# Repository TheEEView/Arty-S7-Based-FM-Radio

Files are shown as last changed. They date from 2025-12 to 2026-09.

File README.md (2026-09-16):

# Arty-S7-Based-FM-Radio
FPGA Based FM Radio with custom RF frontend using an Arty S7 off the shelf development board spanning the 88MHz to 108MHz passband with crisp high-end audio (16-bit stereo). The RF front end downmixes and filters the received FM signal down to 100kHz before the ADC via a neat 4th order Butterworth MFB topology and other goodies.

This is the 2nd major gen design (First generation with 2 iterations were an all in one board with a Spartan 7 onboard), hence the v2 sch/pcb nomenclature. I will release the other version as another project.

The PCB is a 4 layer board with a S/G/G/S stackup using primarily 0402 components and high speed design principles. Routing is on the top and bottom layers only.

Please See docs/fm-radio-sysarch.png for a simple system block design and docs/fm-radio-fpga-arch for the FPGA architecture.

Vivado 2025.2.1, KiCAD 10 and Octave have been used.

Source is available in VHDL (IEEE Std 1076-2019).

This has been a WIP since Dec 2023. 

## How to generate Vivado Project
source logic/impl/create_project.tcl

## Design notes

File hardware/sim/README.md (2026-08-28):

# Analog front end simulation

ngspice models of the `analog_front_end_v2` signal chain, built so the
board can be swept, corner-cased and Monte-Carlo'd before committing to
another spin.

```
./run.sh          # nominal benches, ~5 s
./run.sh mc       # + Monte Carlo (1300 trials), ~13 s
./run.sh e2e      # + end-to-end transient level plan, ~35 s
./run.sh all      # everything
```

Needs only `ngspice` (developed on 42) and python3 for `mcstat.py` —
standard library only, no numpy.

## What is modelled

Component values come from `analog_front_end_v2.kicad_sch`, extracted with
`kicad-cli sch export netlist`, and live in **one** place, `common.inc`.
Refdes names match the schematic. The two shared subnetworks,
`bpf.inc` and `ifchain.inc`, are included by both the nominal and the
Monte Carlo decks so the two cannot drift apart.

```
J1 ─ 5-pole LC BPF ─ U18 ─ U1 ─ U19 ─ U2 ─ U20 ─ U3 ─ U21 ─ U4 ─ U7 ─ T1
                     pad   LNA  pad   LNA  pad   LNA  pad   LNA  pad  balun
                                                                       │
   MCP33131 ◄─ R47/C76 ◄─ U26 MFB ◄─ U25 MFB ◄─ C65/66 ◄─ R33/34 ◄─ LT5560 ◄┘
                                                                     ▲
                                                        ADF4351 ─────┘
```

| bench | what it answers |
|---|---|
| `tb_lna_cal.cir`  | ADL5531 model vs datasheet (gain, NF) |
| `tb_bpf.cir` | RF bandpass shape, insertion loss, out-of-band rejection |
| `tb_rf_chain.cir` | cascade gain and noise figure, antenna to mixer |
| `tb_padsweep.cir` | what the U18 input pad costs in NF |
| `tb_lo_drive.cir` | does the ADF4351 deliver enough LO to the LT5560 |
| `tb_if_chain.cir` | anti-alias response against the real 779.2 ksps plan |
| `tb_e2e.cir` | full time-domain level plan, antenna dBm to ADC volts |
| `mc_bpf.cir` | Monte Carlo: bandpass |
| `mc_rf_chain.cir` | Monte Carlo: cascade gain and NF |
| `mc_if_chain.cir` | Monte Carlo: anti-alias filter |

The operating point is taken from the RTL, not guessed: `fs = 779.2 ksps`
(`mpc33131_adc_driver.vhd`), IF pinned at 100 kHz and the LO one IF below
the station (`adf4351_driver.vhd`), so at full ±75 kHz deviation the
instantaneous IF sweeps 25 – 175 kHz (`fm_demodulator.vhd`).

## Model provenance

Everything in `models/behavioral.lib` is marked `[DS]` (from a datasheet),
`[FIT]` (calibrated by a bench in this directory) or `[ASSUMED]`.

Datasheet-backed:

- **LT5560** — `docs/LT5560f.pdf` Table 2 gives the differential signal
  input as 28.5 + j0.8 Ω at 70 MHz, modelled as 28.5 Ω + 1.8 nH. This
  confirms the board's C59/L13/L14 network: it transforms the 50 Ω balun
  secondary to 28.3 Ω, which is the right target. LO port 180 Ω needing
  240 mV<sub>rms</sub>, also from the datasheet.
- **ADL5531** — 20 dB, NF 2.6 dB, OP1dB +19.5 dBm. The input match is a
  *noiseless* synthesised 50 Ω (a real shunt resistor floors the model at
  NF = 3.0 dB and the part does 2.6 dB); `rnf` and `vsat` are then fitted
  to hit NF and OP1dB. `tb_lna_cal.cir` re-checks both.

Assumed, and worth your review:

- **LT5560 conversion transconductance.** Backed out of the 2.4 dB
  conversion-gain figure *assuming the datasheet test circuit presents a
  400 Ω differential IF load* → `gm = 19.4 mA/V`. The absolute level plan
  in `tb_e2e.cir` scales directly with this: a 3× error moves the clip
  point 10 dB. Everything else (filter shapes, NF, LO drive, all the
  Monte Carlo spreads) is independent of it.
- **LTC6362** GBW 34 MHz and ±1.2 V output swing per pin. The GBW is far
  enough above the 222 kHz corner not to matter; the swing limit *does*
  set the clip point in `tb_e2e.cir`.
- **Inductor Q = 40** at 103 MHz for the 0402 bandpass parts. This matters
  a lot — see below. Set `QL` in `bpf.inc` to whatever your actual parts do.

Not modelled: layout parasitics, and the LT5560's open-collector output
bias current (the real part sources ~6 mA per pin, so R33/R34 = 330 Ω drop
about 2 V from the 5 V rail — a headroom question this deck cannot answer).

## What the nominal sim says

**The bandpass costs 3.1 dB, not 0.5 dB.** With ideal inductors the filter
loses 0.5 dB in band. With Q = 40 it loses 3.1 dB, and the two 500 nH
series-arm inductors (L2, L4) dominate — they carry the most reactance so
they burn the most ESR. That 2.6 dB lands directly on the noise figure.
Set `QL=1e9` in `bpf.inc` to see the ideal case.

**Cascade NF is 10.7 dB, and 5 dB of it is the U18 pad.** The pads are
populated with `PAT1220-C-5DB-T5`. Anything ahead of U1 adds to NF one for
one, and `tb_padsweep.cir` shows exactly that:

```
 pad_dB   chain_gain_dB   cascade_NF_dB
    0          54.06           5.57
    5          49.06          10.71     <- as populated
   10          44.06          15.73
```

**The bandpass is fine but wide.** Geometric centre 102.9 MHz, −3 dB band
90.9 – 116.4 MHz, flat to 0.33 dB across 100 – 106. That is a 25 %
fractional bandwidth, which is why rejection at 88 MHz — the bottom of the
FM band, full of strong local transmitters — is only 10.4 dB. Out at
144 MHz it is 44 dB.

**The anti-alias filter is 222 kHz, not 320 kHz.** The header comment in
`fm_demodulator.vhd` says "320 kHz anti aliasing filter"; the two MFB
sections as built give a −3 dB corner of 222 kHz. The shape is very close
to a 4th-order Butterworth (0.18 dB peaking), slightly steeper than
textbook because the mixer's own R33/R34/C64 pole at ~241 kHz makes the
cascade effectively 5th order. Rejection over 604 – 754 kHz, the band that
folds onto the wanted 25 – 175 kHz IF at 779.2 ksps, is 38.6 dB.

**0.80 dB of tilt across the IF swing.** The filter is 0.14 dB down at
25 kHz and 0.80 dB down at 175 kHz. A slope detector turns amplitude tilt
into demodulated output, so this adds to the ~5 % full-deviation
distortion the RTL header already accounts for.

## Two things worth acting on

**1. The ADF4351 is programmed to under-drive the mixer LO.**
`adf4351_driver.vhd` declares `OUTPUT_POWER : natural := 0` (−4 dBm) and
`toplevel.vhd` does not override it. Through R51/C63/R32/C62 the network
delivers 0.626 V per volt of source EMF, so:

```
  ADF4351 setting   LO port mVrms   (LT5560 wants 240)
     -4 dBm             177          <- default, 2.7 dB short
     -1 dBm             250          marginal
     +2 dBm             352          comfortable
     +5 dBm             498
```

Passing `OUTPUT_POWER => 2` in the `toplevel.vhd` generic map fixes it.
Worth confirming on the bench before changing anything — an under-driven
LT5560 loses conversion gain and degrades NF rather than failing outright,
so it would not show up as a dead radio.

**2. The chain runs out of headroom long before the ADC does.**
`tb_e2e.cir` sweeps antenna power through the whole chain into the ADC pins:

```
 Pant_dBm   IF_pk_V   pct_FS
   -100      0.091      3.6
    -90      0.287     11.5
    -80      0.908     36.3
    -70      2.396     95.8    <- clipped
    -60      2.398     95.9
```

The LTC6362 output swing runs out around −75 dBm at the antenna; U4 hits
its own 1 dB compression near −41 dBm. With a cascade NF of 10.7 dB the
noise floor in a 200 kHz channel is about −110 dBm, so the usable window
is roughly 30 dB wide against an FM environment that spans −100 to
−20 dBm. Strong local stations will overload this front end.

This is the same knob as finding 1: four cascaded 20 dB gain blocks with
only 5 dB pads between them is +49 dB of RF gain. Trading pad values buys
headroom at the cost of NF, and `tb_padsweep.cir` plus `tb_e2e.cir`
together let you price that trade. Note the caveat above — the absolute
clip point scales with the assumed LT5560 conversion gain, so measure the
IF level on a real board before redesigning around it. The *shape* of the
problem (gain distribution) does not depend on that assumption.

## Monte Carlo

Each `mc_*.cir` has a knobs block at the top of its `.control` section:

```
let trials = 500
let tolc   = 0.02      $ capacitors
let toll   = 0.03      $ inductors
let tolq   = 0.30      $ inductor Q spread
let dist   = 0         $ 0 = gaussian truncated at 3 sigma, 1 = uniform
setseed 20260829       $ comment out for a fresh draw each run
```

Both halves of the differential IF pair are drawn independently, which is
what actually happens on a board and what creates the gain-mismatch
spread. Each deck writes `MC,...` CSV lines to stdout; `mcstat.py` turns
those into statistics, histograms and yield against limits:

```
./mcstat.py out/mc_if_chain.csv --limit fold_worst_db:max=-35 --hist f3db_hz
```

Results as built (500 / 300 / 500 trials, gaussian at 3σ):

| metric | mean | σ | p1 … p99 |
|---|---|---|---|
| BPF worst in-band IL | −3.24 dB | 0.34 | −4.16 … −2.54 |
| BPF ripple 100–106 | 0.33 dB | 0.067 | 0.18 … 0.49 |
| BPF rejection at 88 MHz | −10.47 dB | 0.74 | −12.2 … −8.8 |
| chain gain at 103 MHz | 48.97 dB | 0.42 | 47.97 … 49.80 |
| cascade NF at 103 MHz | 10.77 dB | 0.32 | 10.20 … 11.67 |
| AA −3 dB corner | 222.0 kHz | 0.72 k | 220.2 … 223.8 k |
| AA fold-band rejection | −38.71 dB | 0.12 | −38.97 … −38.44 |
| IF tilt at 175 kHz | −0.80 dB | 0.029 | −0.87 … −0.72 |

The filters are not tolerance-limited. The IF chain in particular barely
moves — 0.12 dB of σ on alias rejection — because it is all 1 % resistors
and 2 % C0G in a low-Q topology.

The bandpass insertion-loss spread is driven more by **inductor Q than by
component values**. Re-running `mc_bpf.cir` with `tolq = 0` (Q pinned at
40) drops σ from 0.34 dB to 0.17 dB and pulls the worst trial in from
−5.04 dB to −3.80 dB, so Q spread contributes roughly 0.29 dB of the
0.34 dB in quadrature and the L/C tolerances the remaining 0.17 dB. If you
want insertion loss held tightly, specify Q on L2 and L4 — tightening the
value tolerance buys about half as much.

## Adding a scenario

- **Temperature**: `.options TEMP=` in the deck, or `alter` the values from
  a tempco in the Monte Carlo loop.
- **Different pad values**: edit `PAD_IN` / `PAD_12` / … in `common.inc`.
- **Blocking / two-tone**: add a second `SIN` source in `tb_e2e.cir` at,
  say, 88 MHz and watch the 100 kHz IF amplitude drop as the blocker
  desensitises the chain. The compressing `ADL5531` subckt (not
  `ADL5531_LIN`) is already used there, so intermodulation shows up.
- **A different LT5560 conversion gain**: `XMIX ... LT5560 gm=<value>`.

## ngspice notes

Three things cost time while building this; they are worth knowing.

- `meas ac f3 when h=gpass-3 fall=1` does **not** evaluate the expression.
  It silently measures something else. Normalise first: `let hn = h - gpass`
  then `meas ac f3 when hn=-3 fall=1`.
- Only one `let` per line. `let a=1  let b=2` swallows the rest of the line
  into `a`'s right-hand side and `b` never exists.
- After `noise`, the current plot is the *integrated* noise plot; the
  spectral density is the one before it, so use `setplot previous`.
  `setplot noise1` re-selects the first noise run every time, which
  silently returns stale data inside a loop.
- `unif()` and `gauss()` are not available in the control language in
  ngspice 42; `sgauss(0)` and `sunif(0)` are, and the decks build
  truncated distributions from those.

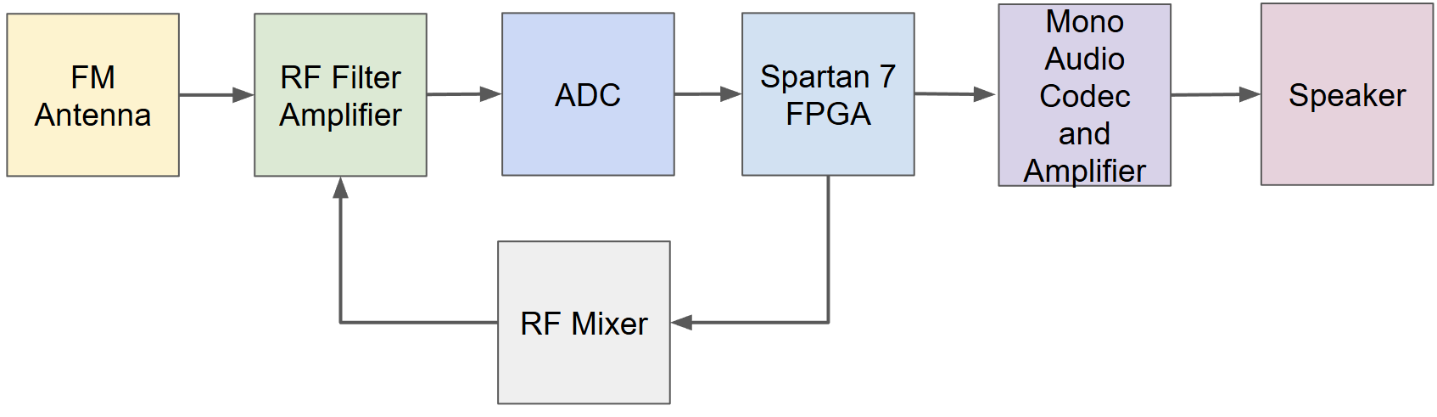
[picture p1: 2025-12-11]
docs/fm-radio-sysarch.png

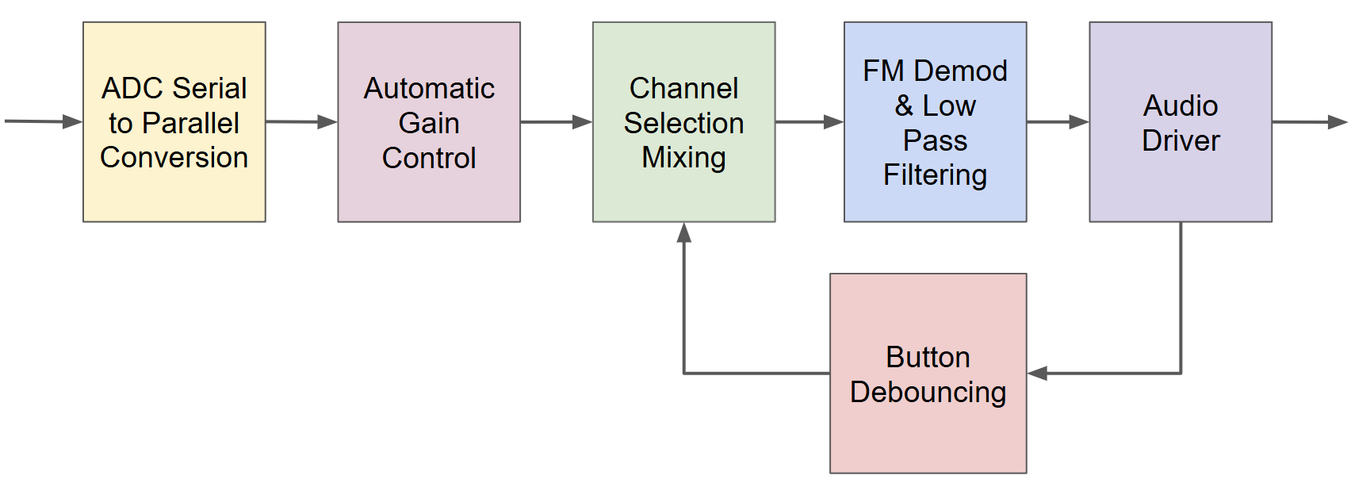
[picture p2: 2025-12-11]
docs/fm-radio-fpga-arch.png

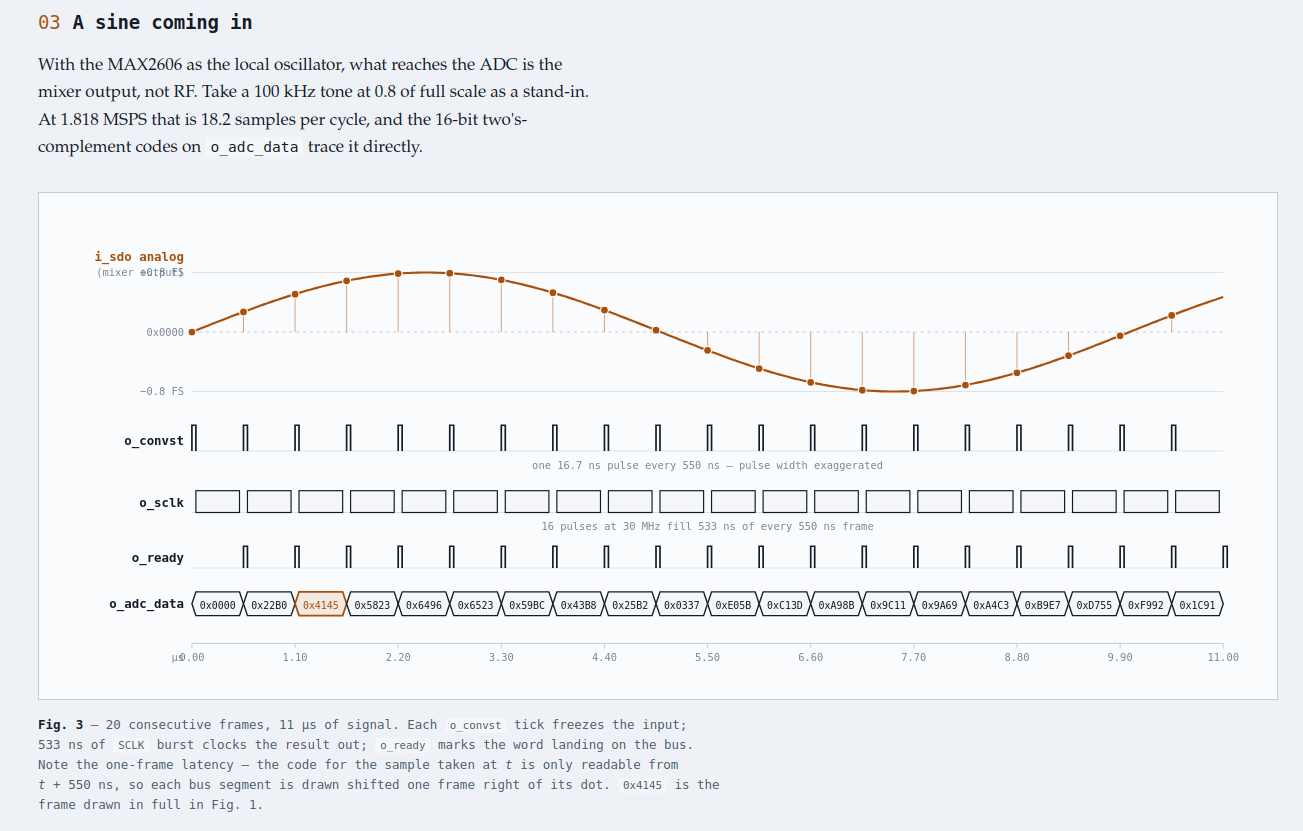
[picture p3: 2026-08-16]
docs/adc_sine_wave.png

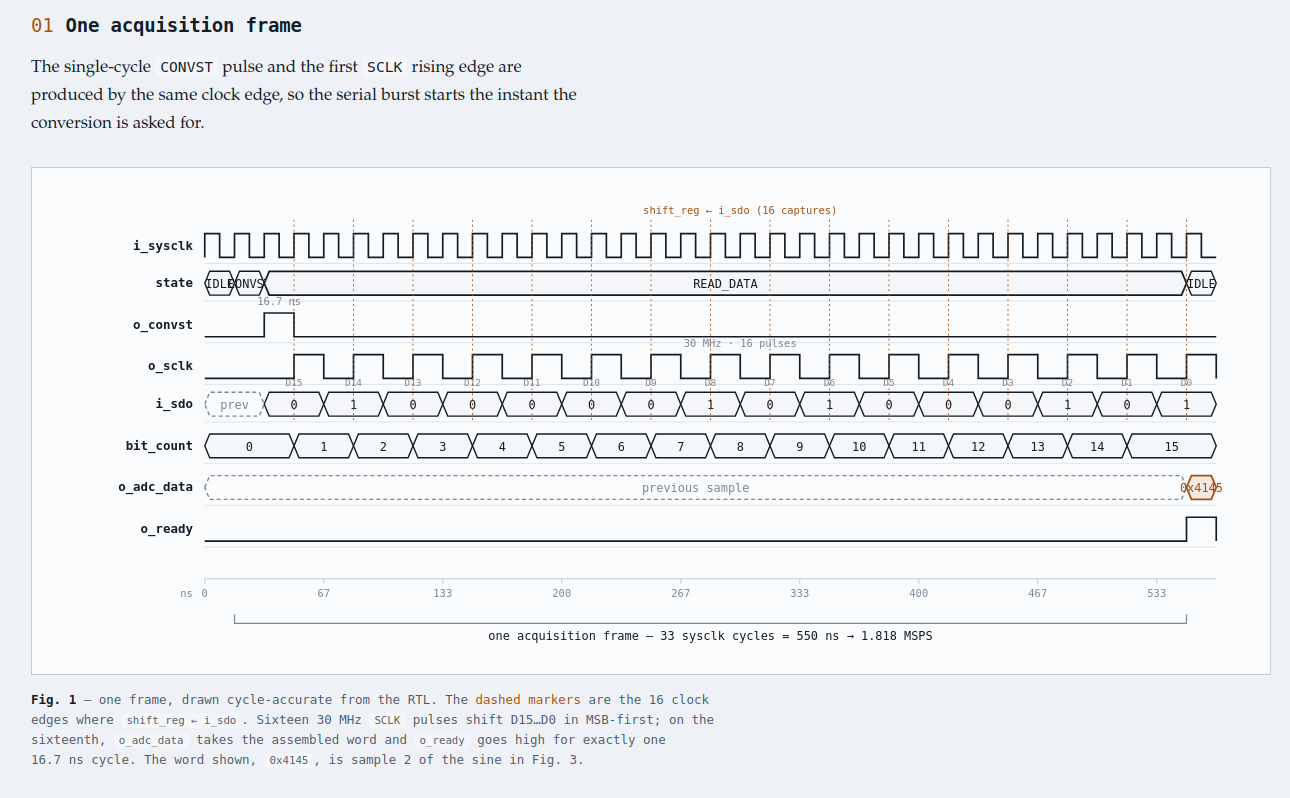
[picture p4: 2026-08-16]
docs/adc_conversion_timing.png

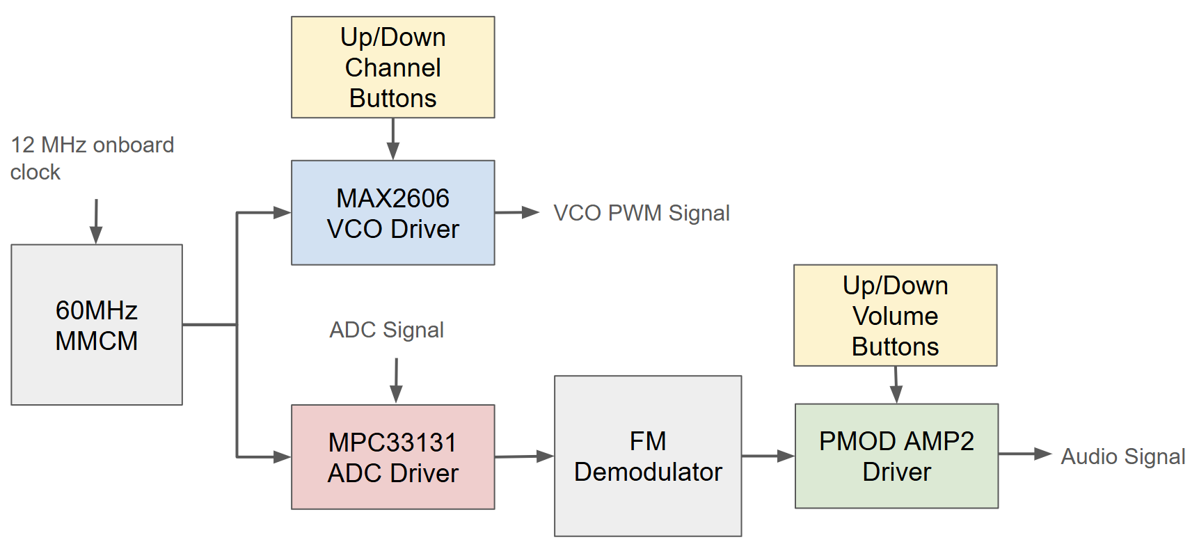
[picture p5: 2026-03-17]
docs/fm-module-composition.png

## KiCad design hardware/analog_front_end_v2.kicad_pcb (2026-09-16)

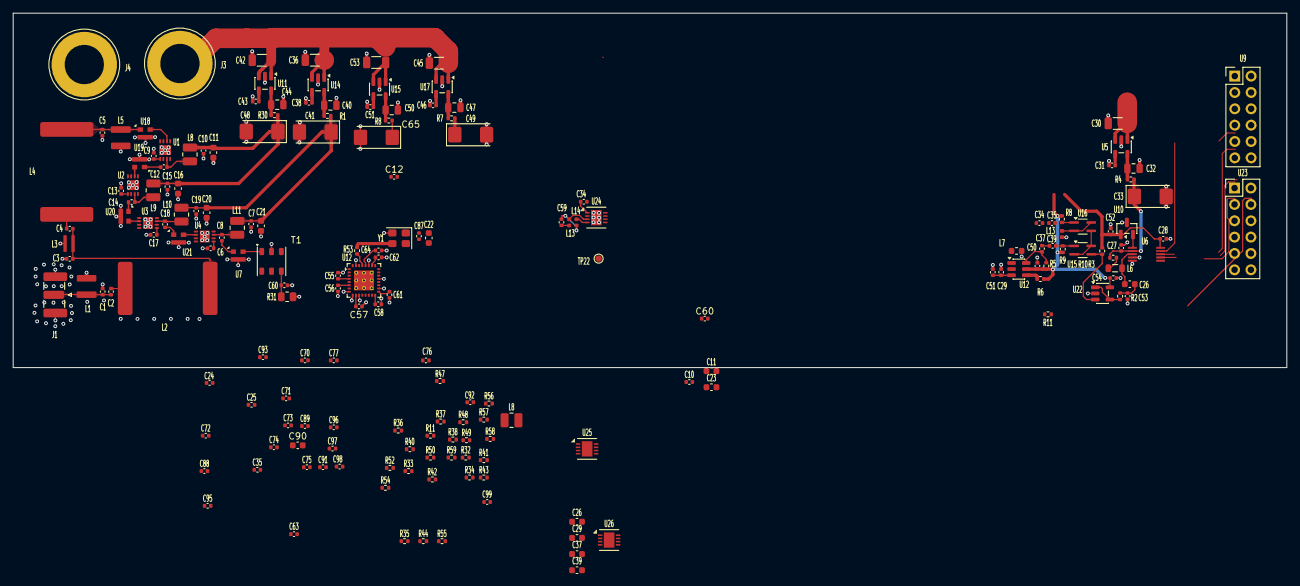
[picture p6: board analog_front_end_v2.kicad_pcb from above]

Board: 4 copper layers, 197.9 x 55.1 mm, 184 parts (0 on the bottom side), 104 nets.

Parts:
C1, C5: 75p_50V; C_0402_1005Metric
C2, C4: 4p8_50V; C_0402_1005Metric
C3: 220p_50V; C_0402_1005Metric
C6, C9, C13, C17, C24, C25, C29, C60: 1n_50V; C_0402_1005Metric
C7, C8, C10, C10#2, C12, C12#2, C14, C15, C18, C19, C31, C34#2, C35, C38, C43, C46, C50, C51#2, C53#2: 10n_25V; C_0402_1005Metric
C11, C11#2, C16, C20, C21, C22, C23, C26, C26#2, C29#2, C37, C39#2: 1u_16V; C_0603_1608Metric
C27, C28, C51, C52, C54, C55, C56, C57, C58, C61, C62, C64, C87, C88, C92, C93, C95, C96, C97, C98, C99: 100n_25V; C_0402_1005Metric
C30, C36, C42, C45, C53: 10u_50V; C_1206_3216Metric
C32, C40, C44, C47, C50#2: 10u_16V; C_0805_2012Metric
C33, C41, C48, C49, C65: 47u_16V; CP_EIA-6032-15_Kemet-U
C34, C35#2, C37#2, C39: 5p1_50V; C_0402_1005Metric
C59: 27p; C_0402_1005Metric
C60#2: 1n; C_0402_1005Metric
C63: 100p_250V; C_0402_1005Metric
C70: 390p; C_0402_1005Metric
C71, C72: 130p; C_0402_1005Metric
C73: 910p; C_0402_1005Metric
C74, C75: 56p; C_0402_1005Metric
C76, C77: 1n8; C_0402_1005Metric
C89: 1n5; C_0402_1005Metric
C90: 15n; C_0603_1608Metric
C91: 150p; C_0402_1005Metric
J1: Conn_Coaxial; SMA_Samtec_SMA-J-P-H-ST-EM1_EdgeMount
J3, J4: Conn_01x01_Socket; Banana_Jack_1Pin
L1, L5: 36n; 1111SQ-36N
L2, L4: 500n; 2929SQ-501GEC
L3: 11n2; 0807SQ-11N
L6: 10n; L_0805_2012Metric
L7: 390n; L_0603_1608Metric
L8, L8#2, L9, L10, L11: 470n; L_1008_2520Metric
L13: 100n; L_0402_1005Metric
L13#2, L14: 18n; L_0402_1005Metric
R1, R4, R7, R8#2, R30: 0R; R_0402_1005Metric
R2, R3, R5, R6, R11#2: 100; R_0402_1005Metric
R8, R9, R10: 3.3k; R_0402_1005Metric
R11: 5.1k; R_0402_1005Metric
R31: 3R0; R_0805_2012Metric
R32: 162R; R_0402_1005Metric
R33, R34: 330R; R_0402_1005Metric
R35, R36, R37, R38, R41, R42, R43, R44: 1k00; R_0402_1005Metric
R40, R56, R57, R58: 4k02; R_0402_1005Metric
R47, R48: 22R0; R_0402_1005Metric
R49, R50: 20k0; R_0402_1005Metric
R52, R59: 50R; R_0402_1005Metric
R53: 33R; R_0402_1005Metric
R54: 1k37; R_0402_1005Metric
R55: 6k19; R_0402_1005Metric
T1: WBC1-1TL 1:1; WBC1-1TLC
TP22: TestPoint; TestPoint_Pad_D1.0mm
U1, U2, U3, U4: ADL5531
U5: LP2985-1.8; SOT-23-5
U6: MCP33131
U7, U18, U19, U20, U21: PAT1220-C-0DB; RF_Attenuator_Susumu_PAT1220
U9, U23: PMOD 2x6 2.54mm pitch; PinHeader_2x06_P2.54mm_Vertical
U10: MAX6002; SOT-23
U11, U14, U15#2: LP2985-5.0; SOT-23-5
U12: MAX2606; SOT-23-6
U12#2: ADF4531; ADF4351_LFCSP-32_5x5mm_P0.5mm_EP3.1x3.1mm
U15, U16: BFP540ESD; SOT-343_SC-70-4_Handsoldering
U17: LP2985-3.3; SOT-23-5
U22: MCP6286; SOT-23-5
U24: LT5560; DFN-8-1EP_3x3mm_P0.5mm_EP1.66x2.38mm
U25, U26: LTC6362; DFN-8-1EP_3x3mm_P0.5mm_EP1.66x2.38mm
Y1: 12.8MHz TCXO; Oscillator_SMD_Abracon_ASE-4Pin_3.2x2.5mm

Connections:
1V8: C27.1, C33.1, R3.1, R4.2, U6.2 (AVDD)
3.3V_PMOD: U9.6, U9.12, U23.6, U23.12
3V3: C22.1, C28.1, C49.1, C50.1, C52.2, C54.1, C55.1, C56.1, C57.1, C58.1, C61.1, C62.1, C64.1, C87.1, R5.2, R6.2, R7.2, R8.1, R9.1, R10.1, R52.2, R59.1, U6.10 (DVIO), U10.1 (IN), U12.5 (VCC), U12#2.4 (CE), U12#2.6 (VP), U12#2.10 (AVDD), U12#2.16 (VVCO), U12#2.17 (VVCO), U12#2.26 (PDBRF), U12#2.28 (DVDD), U12#2.32 (SDVDD), U22.5 (Vdd), Y1.1 (EN), Y1.4 (Vdd)
5V_LNA1: C10.1, C10#2.1, C11.1, C11#2.1, C15.1, C16.1, C48.1, L8.2, L8#2.2, L9.2, R30.2
5V_LNA2: C7.1, C19.1, C20.1, C21.1, C41.1, L10.2, L11.2, R1.2
5V_MIX: C23.1, C24.1, C37.1, C39#2.1, C65.1, C97.1, C98.1, C99.1, R8#2.2, R33.1, R34.2, U24.2 (EN), U24.7 (VCC), U25.3 (V+), U25.7 (~SHDN), U26.3 (V+), U26.7 (~SHDN)
ADC_AIN_N: C77.1, R48.2, U6.4 (AIN-)
ADC_AIN_P: C76.2, R47.2, U6.3 (AIN+)
ADC_CONVST: U6.6 (CONVST), U9.9
ADC_SCLK: U6.8 (SCLK), U9.3
ADC_SDI: U6.9 (SDI), U9.1
ADC_SDO: U6.7 (SDO), U9.7
ADC_VCM: C29#2.1, R2.2, U25.2 (VOCM), U26.2 (VOCM)
ADC_VREF_2V5: R49.1, U6.1 (Vref), U10.2 (OUT)
CP_OUT: C89.1, R54.1, R55.1, U12#2.7 (CPOUT)
GND: C1.2, C3.2, C5.2, C6.2, C7.2, C9.2, C10.2, C10#2.2, C11.2, C11#2.2, C13.2, C15.2, C16.2, C17.2, C19.2, C20.2, C21.2, C22.2, C23.2, C24.2, C26.2, C27.2, C28.2, C29.1, C29#2.2, C30.1, C31.1, C32.1, C33.2, C35.1, C36.1, C37.2, C38.1, C39#2.2, C40.1, C41.2, C42.1, C43.1, C44.1, C45.1, C46.1, C47.1, C48.2, C49.2, C50.2, C50#2.1, C51.2, C51#2.1, C52.1, C53.1, C53#2.2, C54.2, C55.2, C56.2, C57.2, C58.2, C60.2, C60#2.2, C61.2, C62.2, C64.2, C65.2, C76.1, C77.2, C87.2, C88.2, C89.2, C90.2, C91.2, C92.2, C93.2, C97.2, C98.2, C99.2, J1.2 (Ext), J4.1 (Pin_1_1), L1.2, L3.2, L5.2, L7.1, L13.1, R11.2, R31.2, R32.2, R50.1, T1.2 (AB), TP22.1 (1_1), U1.9 (EP), U2.9 (EP), U3.9 (EP), U4.9 (EP), U5.2 (GND), U6.5 (GND), U7.3, U9.5, U9.11, U10.3 (GND), U11.2 (GND), U12.2 (GND), U12#2.8 (CPGND), U12#2.9 (AGND), U12#2.11 (AGNDVCO), U12#2.18 (AGNDVCO), U12#2.21 (AGNDVCO), U12#2.27 (DGND), U12#2.31 (SDGND), U14.2 (GND), U15#2.2 (GND), U17.2 (GND), U18.3, U19.3, U20.3, U21.3, U22.2 (Vss), U23.5, U23.11, U24.9 (PGND), U25.6 (V-), U25.9 (V-), U26.6 (V-), U26.9 (V-), Y1.2 (GND)
IF_N: C95.2, R36.1
IF_P: C96.2, R35.1
LO: C37#2.2, R5.1, U12.6 (OUT+)
LO_100M: C63.1, R59.2, U12#2.12 (RFOUTA+)
MIX_BIAS: C60.1, C60#2.1, R31.1, T1.4 (SC)
unnamed: C2.1, L2.1
unnamed: C3.1, C4.1, L2.2, L3.1
unnamed: C4.2, L4.1
unnamed: C5.1, L4.2, L5.1, U18.1
unnamed: C8.2, U7.1
unnamed: C12.2, C12#2.2, U19.1
unnamed: C14.2, U20.1
unnamed: C18.2, U21.1
unnamed: C26#2.1, C53#2.1
unnamed: C34.1, C35#2.1
unnamed: C34.2, C34#2.2, C63.2, R32.1
unnamed: C37#2.1, C39.1
unnamed: C70.1, R35.2, R37.1, R56.1
unnamed: C70.2, R36.2, R38.1, R40.1
unnamed: C71.1, R37.2, U25.1 (-)
unnamed: C71.2, R41.1, R56.2, U25.4 (+)
unnamed: C72.1, R38.2, U25.8 (+)
unnamed: C72.2, R40.2, R42.1, U25.5 (-)
unnamed: C73.1, R41.2, R43.1, R57.1
unnamed: C73.2, R42.2, R44.1, R58.1
unnamed: C74.1, R43.2, U26.1 (-)
unnamed: C74.2, R47.1, R57.2, U26.4 (+)
unnamed: C75.1, R44.2, U26.8 (+)
unnamed: C75.2, R48.1, R58.2, U26.5 (-)
unnamed: C90.1, R54.2
unnamed: C1.1, C2.2, J1.1 (In), L1.1
unnamed: L6.2, R3.2
unnamed: L13.2, U16.2 (E), U16.4 (E)
unnamed: T1.1 (AA), U7.2
unnamed: C59.2, L14.1, T1.3 (SA)
unnamed: C59.1, L13#2.1, T1.5 (SB)
unnamed: C9.1, U1.5 (CLIN)
unnamed: U1.2 (RFIN), U18.2
unnamed: C12.1, C12#2.1, L8.1, L8#2.1, U1.7 (RFOUT)
unnamed: C13.1, U2.5 (CLIN)
unnamed: U2.2 (RFIN), U19.2
unnamed: C14.1, L9.1, U2.7 (RFOUT)
unnamed: C17.1, U3.5 (CLIN)
unnamed: U3.2 (RFIN), U20.2
unnamed: C18.1, L10.1, U3.7 (RFOUT)
unnamed: C6.1, U4.5 (CLIN)
unnamed: U4.2 (RFIN), U21.2
unnamed: C8.1, L11.1, U4.7 (RFOUT)
unnamed: C31.2, U5.4 (BP)
unnamed: C32.2, R4.1, U5.5 (VOUT)
unnamed: C26#2.2, L6.1
unnamed: C43.2, U11.4 (BP)
unnamed: C44.2, R30.1, U11.5 (VOUT)
unnamed: L7.2, U12.1 (IND)
unnamed: R6.1, U12.4 (OUT-)
unnamed: R52.1, U12#2.13 (RFOUTA-)
unnamed: R11.1, U12#2.22 (RSET)
unnamed: C29.2, C51.1, R11#2.1, U12.3 (TUNE)
unnamed: C38.2, U14.4 (BP)
unnamed: C40.2, R1.1, U14.5 (VOUT)
unnamed: C39.2, R9.2, U15.1 (B)
unnamed: C51#2.2, U15#2.4 (BP)
unnamed: R10.2, U15.3 (C)
unnamed: C50#2.2, R8#2.1, U15#2.5 (VOUT)
unnamed: C35#2.2, R8.2, U16.1 (B)
unnamed: U15.2 (E), U15.4 (E), U16.3 (C)
unnamed: C46.2, U17.4 (BP)
unnamed: C47.2, R7.1, U17.5 (VOUT)
unnamed: R2.1, U22.1 (Vout), U22.4 (Vin-)
unnamed: L13#2.2, U24.3 (IN+)
unnamed: L14.2, U24.4 (IN-)
unnamed: C35.2, U24.8 (LO+)
unnamed: C34#2.1, U24.1 (LO-)
unnamed: C25.1, C96.1, R33.2, U24.6 (OUT+)
unnamed: C25.2, C95.1, R34.1, U24.5 (OUT-)
unnamed: R53.1, Y1.3 (OUT)
PLL_REF: R53.2, U12#2.29 (REFIN)
PLL_TEMP: C93.1, U12#2.19 (TEMP)
PLL_VCOM: C92.1, U12#2.23 (VCOM)
PLL_VREF: C88.1, U12#2.24 (VREF)
VCM_DIV: C26.1, R49.2, R50.2, U22.3 (Vin+)
VCO_DATA: U12#2.2 (DATA), U23.1
VCO_LD: U12#2.25 (LD), U23.7
VCO_LE: U12#2.3 (LE), U23.9
VCO_LOCKDET: U12#2.30 (MUXOUT), U23.10
VCO_SCLK: U12#2.1 (CLK), U23.3
VIN: C30.2, C36.2, C42.2, C45.2, C53.2, J3.1 (Pin_1_1), U5.1 (VIN), U5.3 (ON/~OFF), U11.1 (VIN), U11.3 (ON/~OFF), U14.1 (VIN), U14.3 (ON/~OFF), U15#2.1 (VIN), U15#2.3 (ON/~OFF), U17.1 (VIN), U17.3 (ON/~OFF)
VTUNE: C91.1, R55.2, U12#2.20 (VTUNE)

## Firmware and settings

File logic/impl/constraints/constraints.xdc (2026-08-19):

## Arty S7-50 (xc7s50csga324-1) constraints for the FM radio
## Package pins and schematic names taken from Digilent/digilent-xdc Arty-S7-50-Master.xdc

## 12 MHz onboard oscillator
set_property -dict { PACKAGE_PIN F14   IOSTANDARD LVCMOS33 } [get_ports { i_clk_12 }]; #IO_L13P_T2_MRCC_15 Sch=uclk
create_clock -add -name sys_clk_pin -period 83.333 -waveform {0 41.667} [get_ports { i_clk_12 }];

## Buttons
set_property -dict { PACKAGE_PIN G15   IOSTANDARD LVCMOS33 } [get_ports { i_btn_vol_up }];   #IO_L18N_T2_A23_15 Sch=btn[0]
set_property -dict { PACKAGE_PIN K16   IOSTANDARD LVCMOS33 } [get_ports { i_btn_vol_down }]; #IO_L19P_T3_A22_15 Sch=btn[1]
set_property -dict { PACKAGE_PIN J16   IOSTANDARD LVCMOS33 } [get_ports { i_btn_ch_up }];    #IO_L19N_T3_A21_VREF_15 Sch=btn[2]
set_property -dict { PACKAGE_PIN H13   IOSTANDARD LVCMOS33 } [get_ports { i_btn_ch_down }];  #IO_L20P_T3_A20_15 Sch=btn[3]

## High Speed Pmod Header JA - analog front end board (MCP33131 ADC and ADF4351 LO synthesiser)
set_property -dict { PACKAGE_PIN L17   IOSTANDARD LVCMOS33 } [get_ports { o_adc_sdi }];      #IO_L4P_T0_D04_14 Sch=ja_p[1]
set_property -dict { PACKAGE_PIN M14   IOSTANDARD LVCMOS33 } [get_ports { o_adc_sclk }];     #IO_L5P_T0_D06_14 Sch=ja_p[2]
set_property -dict { PACKAGE_PIN M16   IOSTANDARD LVCMOS33 } [get_ports { i_adc_sdo }];      #IO_L7P_T1_D09_14 Sch=ja_p[3]
set_property -dict { PACKAGE_PIN M18   IOSTANDARD LVCMOS33 } [get_ports { o_adc_convst }];   #IO_L8P_T1_D11_14 Sch=ja_p[4]

## ADF4351 LO synthesiser, three wire SPI plus lock detect, on the remaining JA pins.
## CE is expected to be tied high on the analog front end board rather than driven from here.
set_property -dict { PACKAGE_PIN L18   IOSTANDARD LVCMOS33 } [get_ports { o_pll_clk }];      #IO_L4N_T0_D05_14 Sch=ja_n[1]
set_property -dict { PACKAGE_PIN N14   IOSTANDARD LVCMOS33 } [get_ports { o_pll_data }];     #IO_L5N_T0_D07_14 Sch=ja_n[2]
set_property -dict { PACKAGE_PIN M17   IOSTANDARD LVCMOS33 } [get_ports { o_pll_le }];       #IO_L7N_T1_D10_14 Sch=ja_n[3]
set_property -dict { PACKAGE_PIN N18   IOSTANDARD LVCMOS33 } [get_ports { i_pll_lock }];     #IO_L8N_T1_D12_14 Sch=ja_n[4]

## Pmod Header JD - PmodAMP2 mono audio amplifier, plugged into the top row
## PmodAMP2 pin 1 AIN, pin 2 GAIN, pin 3 NC, pin 4 active low shutdown (PmodAMP2 reference
## manual Table 1), so pin 3 of the header is deliberately left unassigned
set_property -dict { PACKAGE_PIN V15   IOSTANDARD LVCMOS33 } [get_ports { o_monoaudio_pwm }];       #IO_L20N_T3_A07_D23_14 Sch=jd1/ck_io[33]
set_property -dict { PACKAGE_PIN U12   IOSTANDARD LVCMOS33 } [get_ports { o_monoaudio_gain }];      #IO_L21P_T3_DQS_14 Sch=jd2/ck_io[32]
set_property -dict { PACKAGE_PIN T12   IOSTANDARD LVCMOS33 } [get_ports { o_monoaudio_nshutdown }]; #IO_L22P_T3_A05_D21_14 Sch=jd4/ck_io[30]

## TODO: source synchronous timing constraints for the ADC interface.
##
## o_adc_sclk is a 30 MHz divide by two of the 60 MHz MMCM output generated in fabric, and
## i_adc_sdo is launched by the ADC on the SCLK falling edge (t_DO max 9.5 ns at DVIO 3.3 V,
## MCP33131D data sheet Table 1-2). The driver captures SDO one 60 MHz cycle after the SCLK
## rising edge, so the launch to capture path spans two 60 MHz cycles.
##
## Constraining that properly needs a generated clock on o_adc_sclk sourced from the clk_wiz
## output pin, then an input delay on i_adc_sdo referenced to its falling edge, along the lines
## of:
##
##   create_generated_clock -name adc_sclk -source <clk_wiz clk_out_60 pin> -divide_by 2 \
##       [get_ports o_adc_sclk]
##   set_input_delay -clock adc_sclk -clock_fall -max 11.0 [get_ports i_adc_sdo]
##   set_input_delay -clock adc_sclk -clock_fall -min 1.0  [get_ports i_adc_sdo]
##
## The source pin only exists once the clk_wiz IP has been generated, so this is left as a TODO
## rather than committed with a guessed hierarchical path. Until it is in place these pins carry
## no timing check. The capture point was chosen to sit a full 33 ns SCLK period away from the
## ADC launch edge, so there is a lot of margin by construction, but it is not being verified.

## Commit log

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2025-11-24 Add kicad schematics for custom RF front end v2 tailored for Arty S7
    [analog_front_end_v2.kicad_sch]
2025-11-30 Latest schematic change, mostly major cosmetic cleanup for readability
    [analog_front_end_v2.kicad_sch]
2025-11-30 Further cleanups, start making all fonts sizes 40/30/20
    [analog_front_end_v2.kicad_sch]
2025-12-01 Latest schematic cleanups and use 2x through hole connectors for benchtop power suppy VIN and GND
    [analog_front_end_v2.kicad_sch]
2025-12-03 Further cleanups/shrinkage for ease of absorbtion.
    [analog_front_end_v2.kicad_sch]
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2025-12-05 Shrunk RF amp section
    [analog_front_end_v2.kicad_pcb]
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2025-12-06 Annotated all caps with voltage ratings
    [analog_front_end_v2.kicad_sch]
2025-12-07 Updated PCB layout with further size reductions around the amplifier stages
    [analog_front_end_v2.kicad_pcb]
2025-12-07 Make the band pass filtering and amps more compact
    [analog_front_end_v2.kicad_pcb]
2025-12-09 Latest PCB Artwork changes
    [analog_front_end_v2.kicad_pcb]
2025-12-09 Make RF frontend super compact
    [analog_front_end_v2.kicad_pcb]
2025-12-11 Update notes/decisions in schematics/pcb for clarity
    [analog_front_end_v2.kicad_pcb, analog_front_end_v2.kicad_sch]
2025-12-11 Reduce size of all silkscreen to 0.4mm for easier placement
    [analog_front_end_v2.kicad_pcb]
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2025-12-11 Minor touchups to via placements to bring them as close as possible to the pads for minimized parasitics
    [analog_front_end_v2.kicad_pcb]
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2025-12-15 Routing for 5V_LNA and VIN connections. Also added note to add GND Planes for L2/L2
    [analog_front_end_v2.kicad_pcb]
2025-12-16 Begin adding tolerance information to passives
    [analog_front_end_v2.kicad_sch]
2025-12-17 Annotate tolerance of all caps in sch
    [analog_front_end_v2.kicad_sch]
2025-12-20 Annotate resistor tolerances on the schematic
    [analog_front_end_v2.kicad_sch]
2025-12-20 Annotate tolerance values for missed resistors
    [analog_front_end_v2.kicad_sch]
2025-12-22 Begin adding I/Q component handling
    [analog_front_end_v2.kicad_sch]
2025-12-22 Hooked up VCC, VCTRL and IFDET pins of the LT5546EUF
    [analog_front_end_v2.kicad_sch]
2025-12-22 Assign MOC/Size/Tolerances to LT5546EUF passives
    [analog_front_end_v2.kicad_sch]
2025-12-22 Minor cleanups around the LT5546EUF
    [analog_front_end_v2.kicad_sch]
2025-12-25 Finished off most of the LT5546 connections, just the demod outputs & opamps to go
    [analog_front_end_v2.kicad_sch]
2025-12-26 Start adding analog signal processing post demod I/Q signals
    [analog_front_end_v2.kicad_sch]
2025-12-26 Further work on IF filters/cleanup of old now redundant 8-bit ADC circuitry
    [analog_front_end_v2.kicad_sch]
2025-12-27 Finish off IF filter section
    [analog_front_end_v2.kicad_sch]
2025-12-28 Begin drawing I/Q ADC section
    [analog_front_end_v2.kicad_sch]
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2025-12-29 Further RF front end miniaturization
    [analog_front_end_v2.kicad_pcb]
2025-12-30 Further optimisations of the RF frontend
    [analog_front_end_v2.kicad_sch]
2025-12-30 Improve regulation in power supplies and hookup 7 segment supply in sch, last part remaining is where to connect the 7segs to the Arty S7
    [analog_front_end_v2.kicad_sch]
2026-01-05 Assigning resistor and cap MOC's within the op-amps section
    [analog_front_end_v2.kicad_sch]
2026-01-08 Assign remaining passive MOC's
    [analog_front_end_v2.kicad_sch]
2026-01-10 Remove 7 seg's from schematic/PCB, it is extra unneeded noise
    [analog_front_end_v2.kicad_pcb, analog_front_end_v2.kicad_sch]
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2026-01-13 Add PCB notes on via stiching/guarding and implement it around the RF path
    [analog_front_end_v2.kicad_pcb]
2026-01-17 Remove overly complex I/Q demod and post amplification. Reduce to simply 6x LNA's instead to head towards 0dBm received
    [analog_front_end_v2.kicad_sch]
2026-01-19 Shrink down all schematic connections for a simpler painting
    [analog_front_end_v2.kicad_sch]
2026-01-19 Reduce LNA total gain down to 100dB, should be enough to support -93dBm received signals in Melbourne with plenty of signal at the ADC.
    [analog_front_end_v2.kicad_sch]
2026-01-22 Latest changes to add in a new diffamp and simplify the schematic for readability
    [analog_front_end_v2.kicad_sch]
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2026-03-05 Final cleanup and GND planes for layers 2 and 3
    [analog_front_end_v2.kicad_pcb]
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2026-03-05 Update textual comments and fix a via annular ring setting
    [analog_front_end_v2.kicad_pcb]
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2026-03-10 Add in toplevel stubs for reset processing and VCO/ADC instantiations
2026-03-11 Reorganized project structure: moved source and constraints into folders
    [analog_front_end_v2.kicad_pcb, analog_front_end_v2.kicad_sch]
2026-03-12 Add volume up/down and channel inc/dec buttons and use inverted mmcm lock signal for power on reset until mmcm is stable
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2026-03-21 Updated KiCAD prj/sch/pcb files that were sent for manufacturing
    [analog_front_end_v2.kicad_pcb, analog_front_end_v2.kicad_sch]
2026-03-22 Updated KiCAD Prj,sch,pcb files for 2.54mm PMOD male connector
    [analog_front_end_v2.kicad_pcb, analog_front_end_v2.kicad_sch]
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2026-08-12 Move to KiCAD 10 and improve schematics readability
    [analog_front_end_v2.kicad_pcb, analog_front_end_v2.kicad_sch]
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2026-08-18 Remove old VCO and start adding new one
    [analog_front_end_v2.kicad_sch]
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2026-08-24 Add symbol for ADF4351 and update bandpass to 100 to 106MHz
    [analog_front_end_v2.kicad_sch]
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2026-08-25 Populate VCO and add butterworth filter immediately after before the ADC
    [analog_front_end_v2.kicad_sch]
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2026-08-27 Use 2nd 5V LNA for the 3rd and 4th amps
    [analog_front_end_v2.kicad_sch]
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2026-08-31 Assign more values to downmixer and butterworth filters
    [analog_front_end_v2.kicad_sch]
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2026-09-16 Update more passive MOC/Size/tolerances across the schematic
    [analog_front_end_v2.kicad_pcb, analog_front_end_v2.kicad_sch]
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2026-09-16 More routing and move frontend inductor to be perpendicular
    [analog_front_end_v2.kicad_pcb, analog_front_end_v2.kicad_sch]
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
